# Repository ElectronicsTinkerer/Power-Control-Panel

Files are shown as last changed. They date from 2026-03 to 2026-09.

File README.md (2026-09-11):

# Custom Remote-Controlled Power Distribution Panel

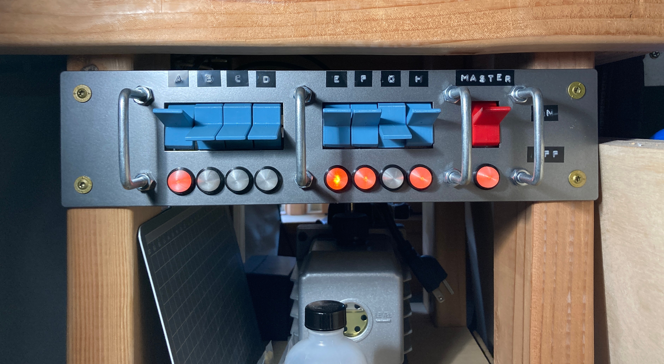
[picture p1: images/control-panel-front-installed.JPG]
Front image of the control panel, showing eight blue switches, grouped by fours, and a single red switch labeled "master" on the right side. Each group is separated by square U-bolts, acting as guards or handles to the panel. Below the switches are large orange indicator bulbs.


The control panel provides control over eight individually switched outlets for managing the numerous gizmoes plugged in to your workbench. In addition, there is a master switch which overrides the rest of the panel for shutting down all outputs.

The device is constructed of two components. The first (pictured above) is the control panel. This contains a PCB that uses a shift register to parallel load the state of the input switches and send them over an ethernet-style cable to the second component, the relay board. The relay board is responsible for generating the clock and load signals used by the control panel. It also shifts in the data from the control panel and drives a bank of eight relays to control attached devices.

All the design files are included in this repo. For more background and pictures, checkout [my website](https://zrcn.org/power-control-panel.html).

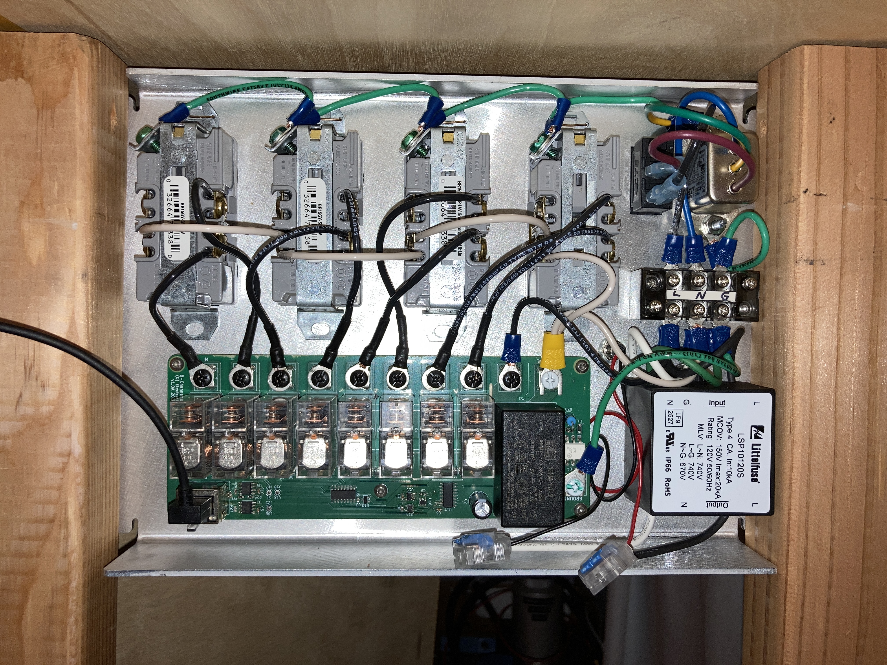
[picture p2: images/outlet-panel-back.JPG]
Relay board connected to outlets on the top side and protection circuitry on the right.

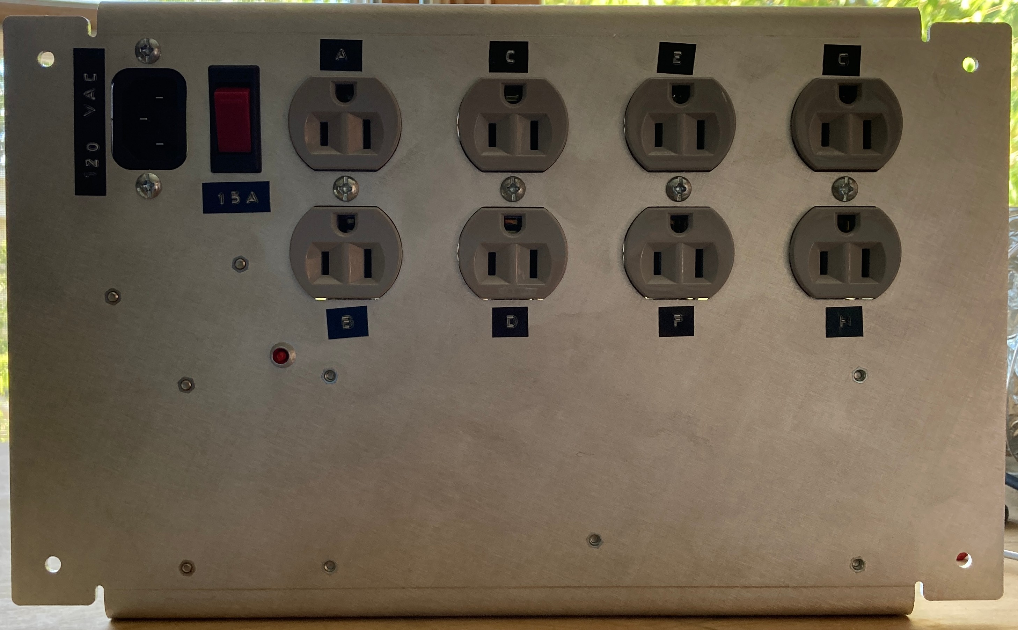
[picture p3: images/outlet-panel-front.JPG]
Front of the outlet panel, showing eight outlets, one IEC power inlet plug, the thermal breaker, and the surge supressor status light


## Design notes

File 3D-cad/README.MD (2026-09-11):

# 3D CAD

This directory contains all the 2D/3D models for components which are 3D printed or made from sheet metal.

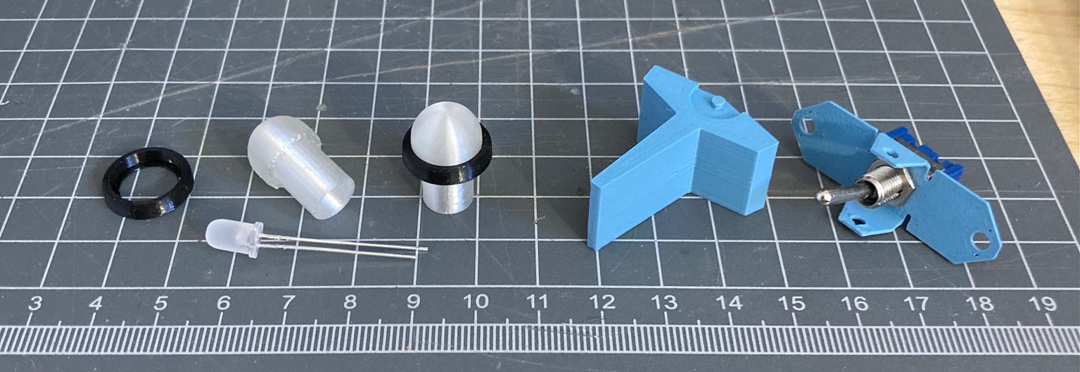
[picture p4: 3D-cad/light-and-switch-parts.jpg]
Image showing the 3D components in this directory against a 1cm grid.
 

```
.
├── 5mm-light-cover-decorator-ring.FCStd       # Black ring around the LED diffuser
├── 5mm-light-cover-decorator-ring-Fillet.step 
├── 5mm-light-cover.FCStd                      # LED diffuser
├── 5mm-light-cover-Revolve.step
├── Front-Panel-Assy.FCStd                     # Minimal assembly to check part alignment
├── Front-Panel.FCStd                          # User-facing front panel
├── Front-Panel-Unfold.dxf                     # FP. Order 0.1" sheet metal
├── Front-Panel-Rear-Plate.FCStd               # Mounting plate for switches and FP PCB
├── Front-Panel-Rear-Plate-Unfold.dxf          # FP PCB plate. 0.1" 5052 Al, K=0.4, R=0.125", 90 degree bend
├── Outlet-Panel.FCStd                         # Panel for Relay Board and Outlets.
├── Outlet-Panel-Assy.FCStd                    # Minimal assembly to check component alignment
├── Outlet-Panel-Unfold.dxf                    # Panel for Relay Board and Outlets. 0.1" 5052 Al, K-0.4 R=0.125", 90 degree bend, M3 hardware
├── Paddle-Switch-Bracket-Cut2.step            # Mount/pivot bracket for paddle switch
├── Paddle-Switch-Bracket-Cut.step             # Mount/pivot, slightly wider for 3D printing
├── Paddle-Switch-Bracket.FCStd
├── Paddle-Switch-Bracket-Unfold.dxf           # Mount/pivot. mild steel 0.03" thick K=0.36, 90 degree bends
├── Paddle-Switch-Bracket-inner-die.FCStd
├── Paddle-Switch-Bracket-inner-die-v1.0A0.step # "Die" for forming the Paddle-Switch-Bracket
├── Paddle-Switch-Cut.step                     # Paddle switch handle, "square"
├── Paddle-Switch.FCStd
├── Paddle-Switch-Fillet.step                  # Paddle switch handle, "rounded"
├── Relay-PCB-Insulator.FCStd                  # Electrical insulator for under the relay board
├── Relay-PCB-Insulator-Unfold.dxf             # 0.03" polypropylene
├── serial-relay-panel.FCStd                   # Reference (potentially out of date) 3D model of the relay PCB
├── serial-relay-panel.step
├── serial-switch-panel.FCStd                  # Reference (potentially out of date) 3D model of the input PCB
└── serial-switch-panel.step
```

Everything has been designed in FreeCAD, but this directory also contains the STEP file from the latest "working" version of the file so you shouldn't need to edit the FCStd files unless you want to tweak them.

## Print Settings

I have printed my copies in PETG (Prusa and Creality) and the following settings work well with a 0.4mm nozzle.

**light cover decorator ring**

* Color: black
* 0.1mm layer height.

**light cover**

* Color: translucent
* 0.1mm layer height
* Print facing upwards so it looks like a small mushroom. Use supports under the outer brim. No supports needed on the inside.
* 100% infill, concentric

**paddle switch bracket**

* Color: any ("Chalky blue" pictured above)
* 0.1mm layer height
* Add support material within the pivot holes on either side. You may need a 3/32" bit to clean the hole afterwards.
* Wait for the bed to cool completely before removing!
* Note: there is also a `.dxf` file if you want this made from sheet metal. See the dir listing comments for details.

**paddle switch bracket die**

* Color: any
* 0.15mm or smaller layer height
* 100% infil
* I used PETG, but I imagine other materials would work fine.
* This is not a piece used in the final assembly, but rather a tool to enable bending of the paddle switch bracket, should you decide to have it made from sheet metal. To do this, print the die and screw down the bracket to the die at one end plus the center hole. Make sure all holes are aligned. Now use a hammer and bend the tabs down until they are nearly flush with the sides of the die. I was able to get fairly consistent results at about 2-3 minute cycle time per switch bracket but YMMV. (Alternatively, just have the sheet metal fab house bend these).

**paddle switch**

* Color: any ("Chalky blue" pictured above)
* 0.1mm layer height
* Print on its side like the above image
* Use supports for all overhangs (around the pivot and the inside ledge)

## Non-printed items

To assemble the outlet panel, you'll need the following components:

* `LSP10120S` from Littelfuse (surge supressor, wire in parallel mode)
* `FL1M-6CW-4-R110V` or any other line voltage panel-mount indicator
* `3-2486200-9` from TE Connectivity or similar panel mount circuit breaker
* `15SRB8-W` from TE Connectivity or similar 15A IEC inlet plug

My recommended power cord is the `P007-006-15D` as it's rated for 15A and has a nice 90-degree plug for fitting behind the workbench.

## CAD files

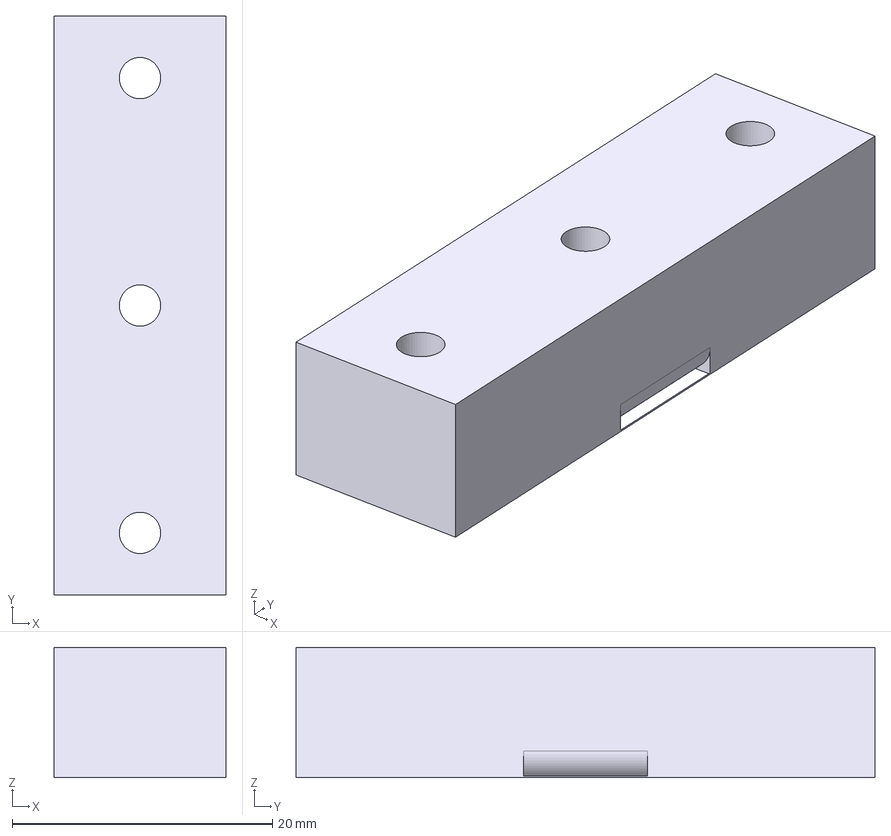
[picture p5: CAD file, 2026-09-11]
3D-cad/Paddle-Switch-Bracket-inner-die-v1.0A0.step
13.2 x 44.5 x 10.0 mm

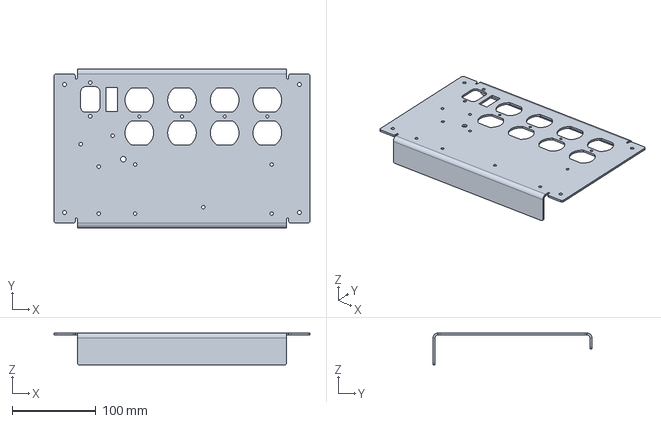
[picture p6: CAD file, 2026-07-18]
3D-cad/Outlet-Panel.FCStd
304.8 x 189.2 x 38.1 mm

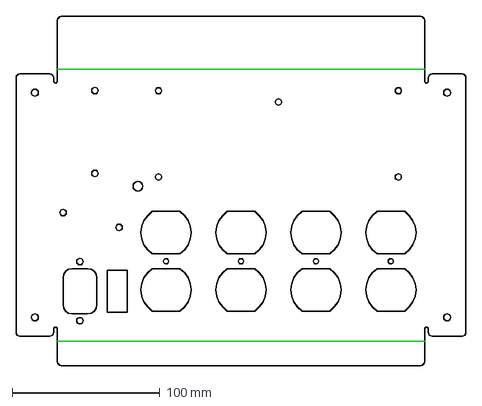
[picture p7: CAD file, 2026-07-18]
3D-cad/Outlet-Panel-Unfold.dxf
304.8 x 236.7 mm

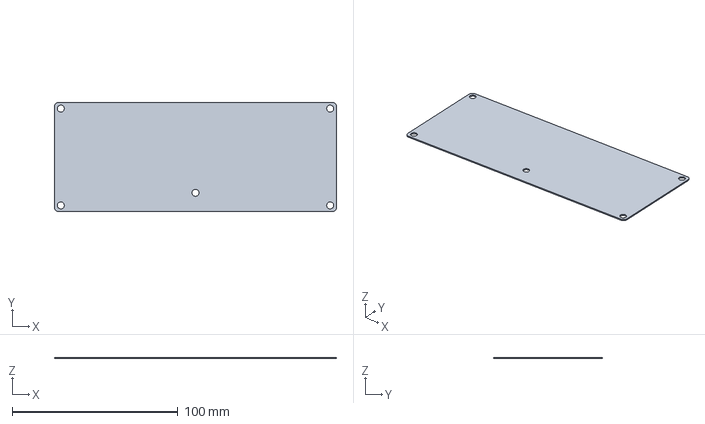
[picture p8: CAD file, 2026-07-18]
3D-cad/Relay-PCB-Insulator.FCStd
170.2 x 66.0 x 0.762 mm

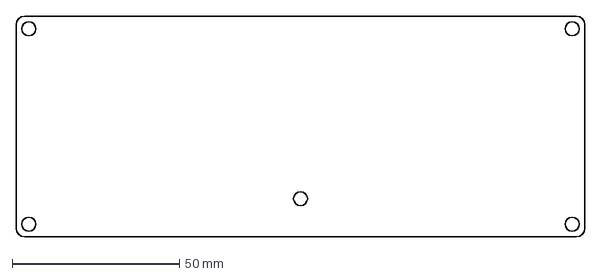
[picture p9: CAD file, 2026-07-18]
3D-cad/Relay-PCB-Insulator-Unfold.dxf
170.2 x 66.0 mm

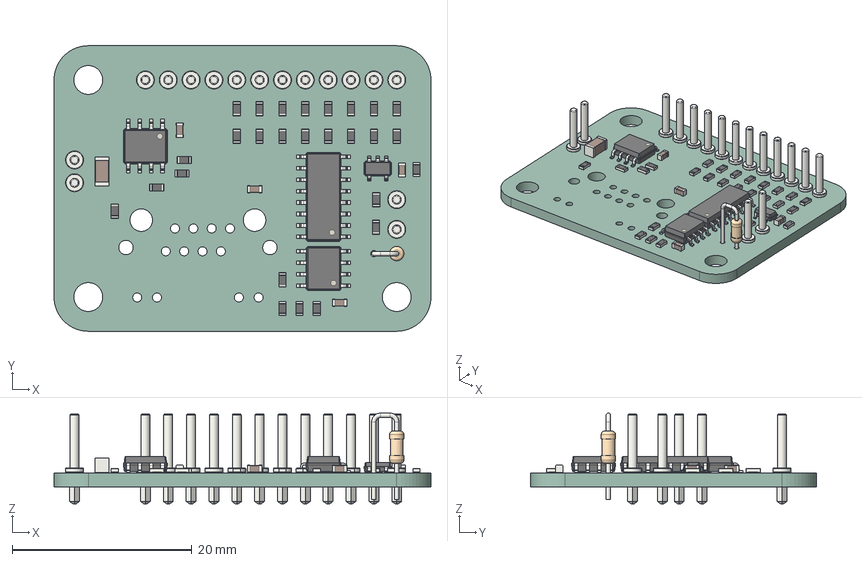
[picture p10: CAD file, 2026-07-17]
3D-cad/serial-switch-panel.step
41.9 x 31.8 x 10.1 mm
R_0603_1608Metric x 27
Pin_d1.0mm_L10.0mm x 16
C_0603_1608Metric x 4
SOIC-8_3.9x4.9mm_P1.27mm x 2
TSOP-5_1.65x3.05mm_P0.95mm
R_Axial_DIN0204_L36mm_D16mm_P254mm_Vertical
C_1206_3216Metric
SOIC-16_3.9x9.9mm_P1.27mm
serial-switch-panel_PCB

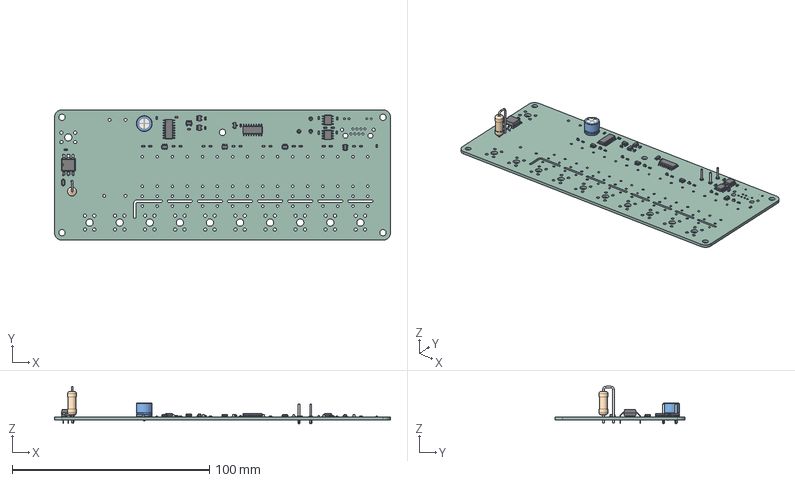
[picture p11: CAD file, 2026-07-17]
3D-cad/serial-relay-panel.step
170.2 x 66.0 x 19.0 mm
R_0603_1608Metric x 14
LED_0603_1608Metric x 8
C_Radial_D80mm_H70mm_P350mm
SC-74-6_1.55x2.9mm_P0.95mm x 4
SOIC-8_3.9x4.9mm_P1.27mm x 2
Pin_d1.0mm_L10.0mm x 3
SOT-23-5 x 3
C_0603_1608Metric x 8
R_Axial_DIN0414_L119mm_D45mm_P508mm_Vertical
DIP-6_W10.16mm
SOIC-16_3.9x9.9mm_P1.27mm x 2
D_SOD_123F
SOT-23-3
serial-relay-switch_PCB

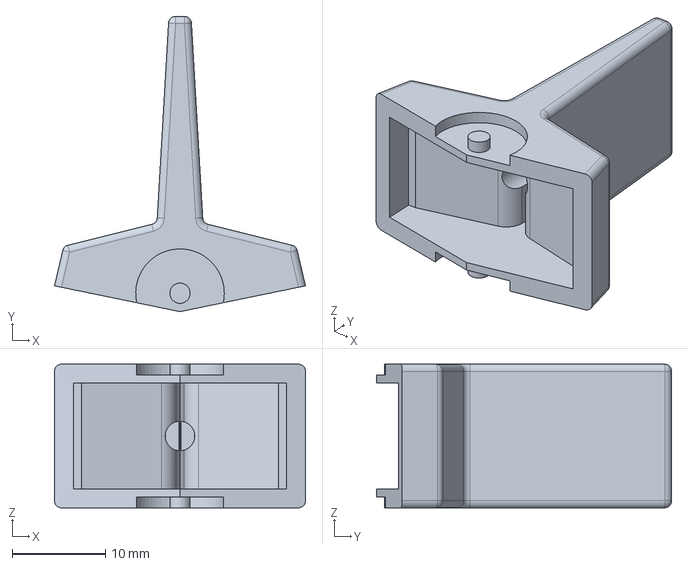
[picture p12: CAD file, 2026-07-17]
3D-cad/Paddle-Switch.FCStd
27.0 x 31.8 x 15.4 mm

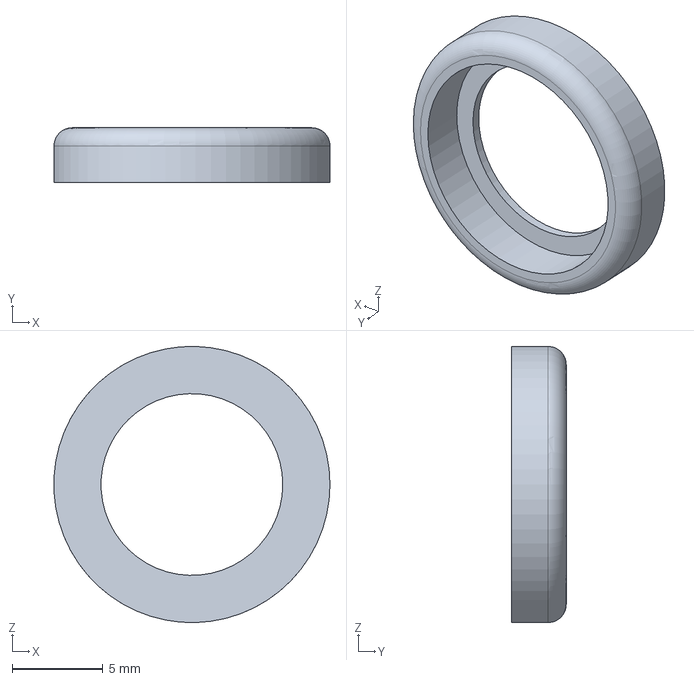
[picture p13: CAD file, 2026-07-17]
3D-cad/5mm-light-cover-decorator-ring.FCStd
15.2 x 3.00 x 15.2 mm

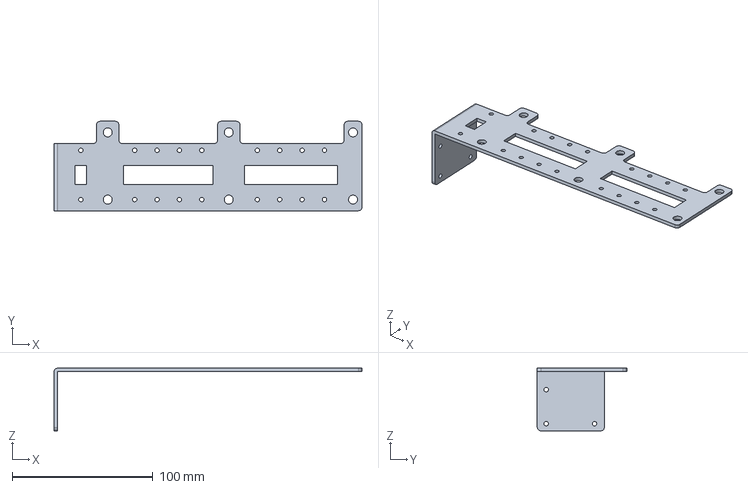
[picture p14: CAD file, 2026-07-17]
3D-cad/Front-Panel-Rear-Plate.FCStd
218.4 x 63.5 x 44.4 mm

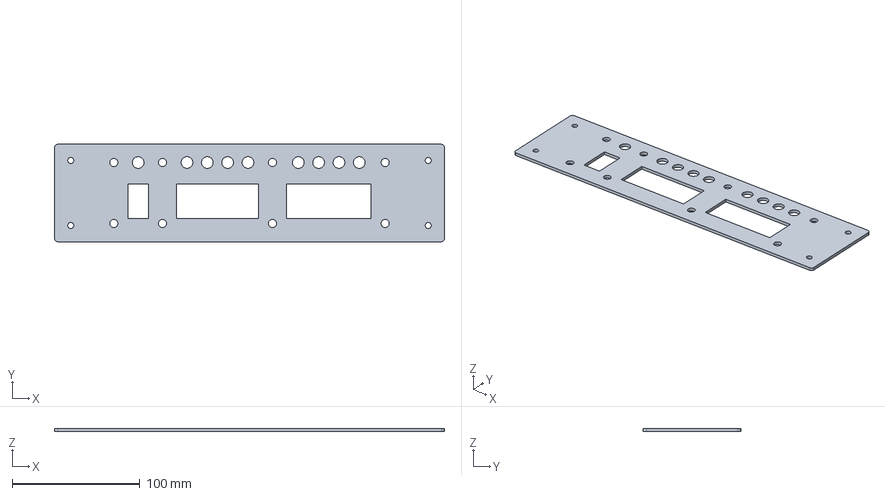
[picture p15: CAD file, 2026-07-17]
3D-cad/Front-Panel.FCStd
304.8 x 76.2 x 2.54 mm

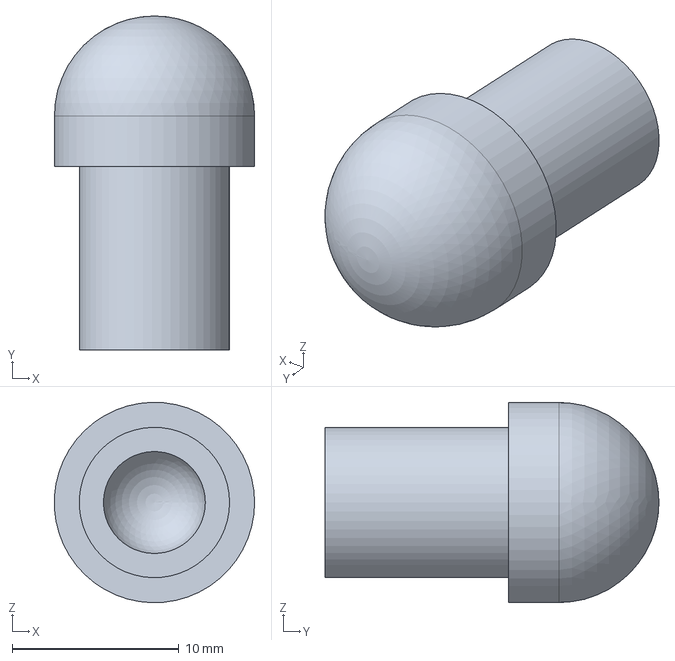
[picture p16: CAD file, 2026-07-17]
3D-cad/5mm-light-cover.FCStd
12.0 x 20.0 x 12.0 mm

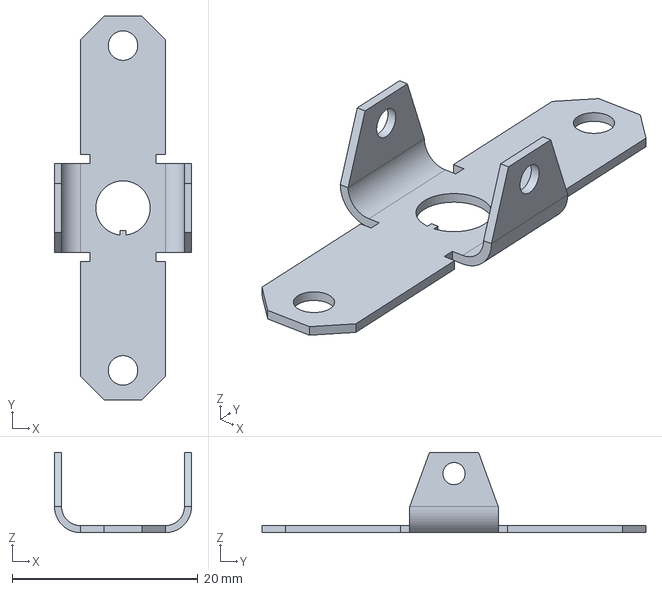
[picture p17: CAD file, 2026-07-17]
3D-cad/Paddle-Switch-Bracket.FCStd
14.7 x 41.3 x 8.64 mm

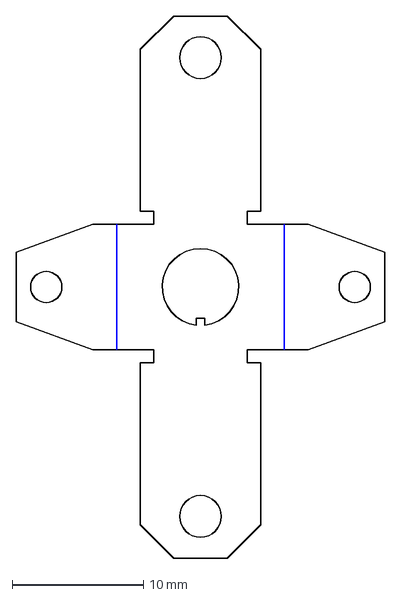
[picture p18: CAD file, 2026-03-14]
3D-cad/Paddle-Switch-Bracket-Unfold.dxf
28.1 x 41.3 mm

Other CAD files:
3D-cad/Outlet-Panel-Assy.FCStd
3D-cad/Front-Panel-Assy.FCStd
3D-cad/Paddle-Switch-Bracket-inner-die.FCStd
3D-cad/Front-Panel-Rear-Plate-Unfold.dxf
3D-cad/5mm-light-cover-Revolve.step
3D-cad/5mm-light-cover-decorator-ring-Fillet.step
3D-cad/Front-Panel-Unfold.dxf
3D-cad/Paddle-Switch-Bracket-Cut.step
3D-cad/Paddle-Switch-Bracket-Cut2.step
3D-cad/Paddle-Switch-Cut.step
3D-cad/Paddle-Switch-Fillet.step
3D-cad/serial-relay-panel.FCStd
3D-cad/serial-switch-panel.FCStd

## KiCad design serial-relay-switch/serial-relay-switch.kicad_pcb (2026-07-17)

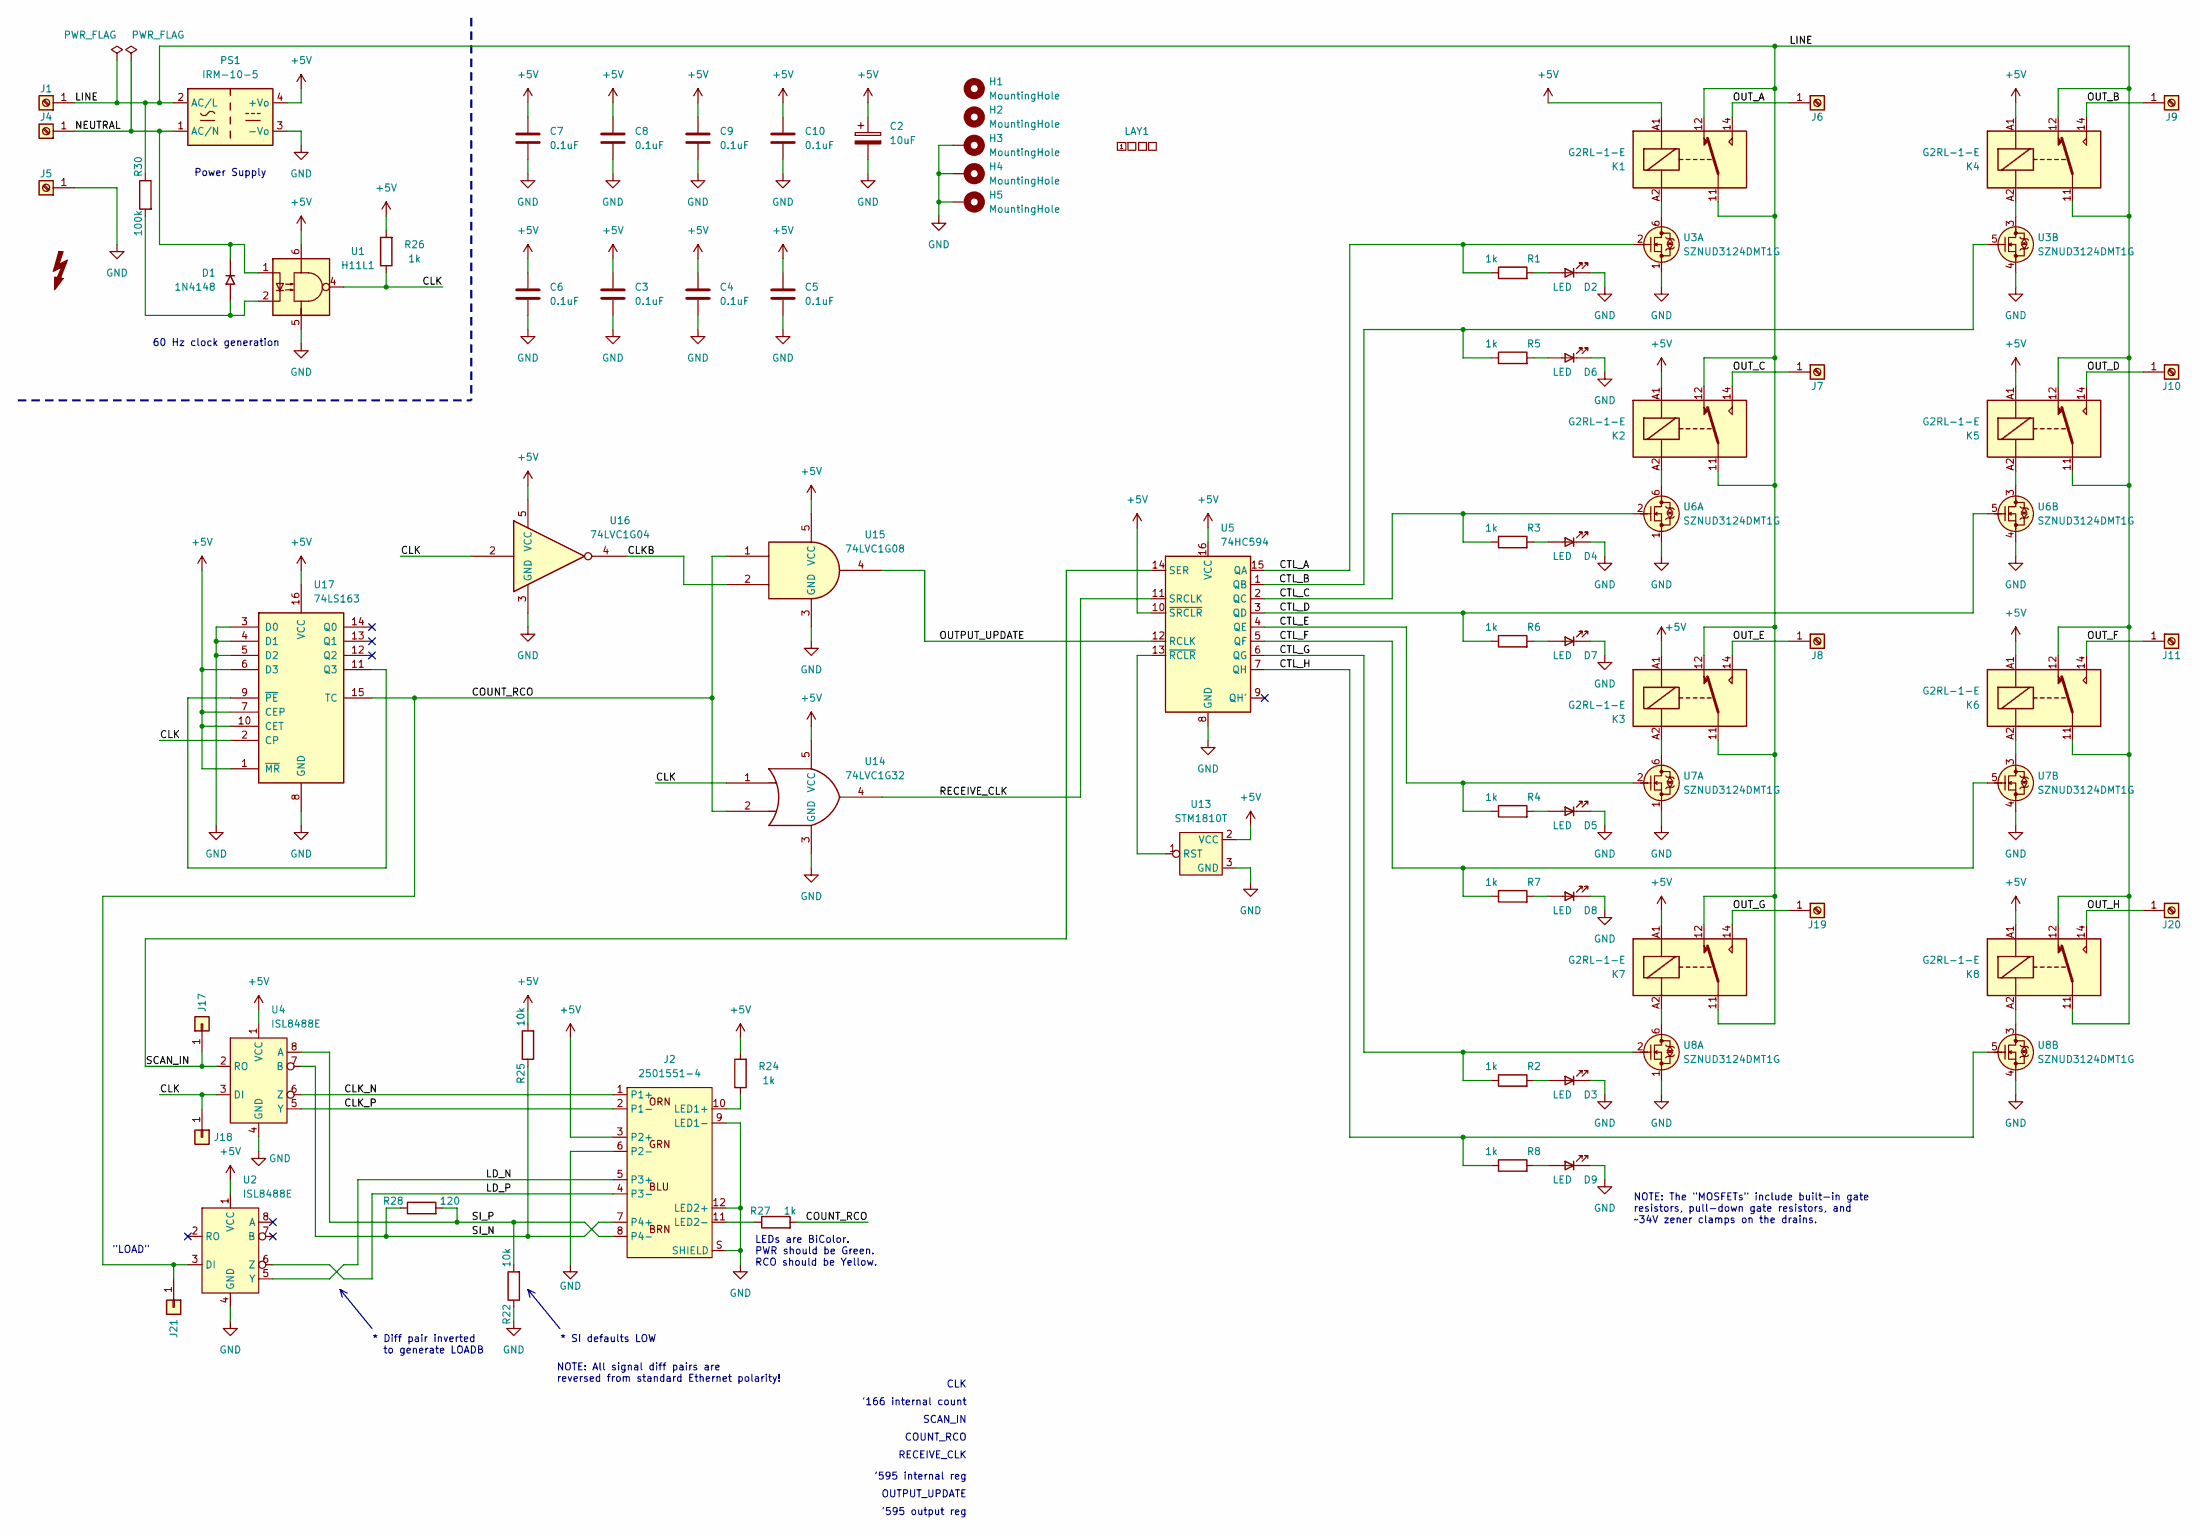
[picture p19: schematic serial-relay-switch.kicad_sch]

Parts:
C2: 10uF; C_Radial_D8.0mm_H7.0mm_P3.50mm
C3, C4, C5, C6, C7, C8, C9, C10: 0.1uF; C_0603_1608Metric
D1: 1N4148; D_SOD-123F
D2, D3, D4, D5, D6, D7, D8, D9: LED; LED_0603_1608Metric
H1, H2: MountingHole; MountingHole_3.2mm_M3_Keepout
H3, H5: MountingHole; MountingHole_3.2mm_M3_ISO14580_Pad_TopBottom
H4: MountingHole; MountingHole_3.2mm_M3_DIN965_Pad_TopBottom
J1, J4, J5, J6, J7, J8, J9, J10, J11, J19, J20: Screw_Terminal_01x01; ScrewTerminal_Keystone_8195
J2: 2501551-4; EthernetJack_TE_2501551-4
J17, J18, J21: Conn_01x01; Pin_D1.0mm
K1, K2, K3, K4, K5, K6, K7, K8: G2RL-1-E; Relay_SPDT_Omron_G2RL-1-E
LAY1: LayerMarker_2_3.81x2.54mm_TextH1mm_P1.27mm_BottomMirrored
PS1: IRM-10-5; Converter_ACDC_MeanWell_IRM-10-xx_THT
R1, R2, R3, R4, R5, R6, R7, R8, R24, R26, R27: 1k; R_0603_1608Metric
R22, R25: 10k; R_0603_1608Metric
R28: 120; R_0603_1608Metric
R30: 100k; R_Axial_DIN0414_L11.9mm_D4.5mm_P5.08mm_Vertical
U1: H11L1; DIP-6_W10.16mm_LongPads
U2, U4: ISL8488E; SOIC-8_3.9x4.9mm_P1.27mm
U3, U6, U7, U8: SZNUD3124DMT1G; SC-74-6_1.55x2.9mm_P0.95mm
U5: 74HC594; SOIC-16_3.9x9.9mm_P1.27mm
U13: STM1810T; SOT-23-3
U14: 74LVC1G32; SOT-23-5
U15: 74LVC1G08; SOT-23-5
U16: 74LVC1G04; SOT-23-5
U17: 74LS163; SOIC-16_3.9x9.9mm_P1.27mm

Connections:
+5V: C2.1, C3.1, C4.1, C5.1, C6.1, C7.1, C8.1, C9.1, C10.1, J2.3 (P2+), K1.A1, K2.A1, K3.A1, K4.A1, K5.A1, K6.A1, K7.A1, K8.A1, PS1.4 (+Vo), R24.2, R25.2, R26.2, U1.6, U2.1 (VCC), U4.1 (VCC), U5.10 (~SRCLR), U5.16 (VCC), U13.2 (VCC), U14.5 (VCC), U15.5 (VCC), U16.5 (VCC), U17.1 (~MR), U17.6 (D3), U17.7 (CEP), U17.10 (CET), U17.16 (VCC)
/CLK: J18.1 (Pin_1_1), R26.1, U1.4, U4.3 (DI), U14.1, U16.2, U17.2 (CP)
/CLKB: U15.2, U16.4
/CLK_N: J2.1 (P1+), U4.6 (Z)
/CLK_P: J2.2 (P1-), U4.5 (Y)
/COUNT_RCO: J21.1 (Pin_1_1), R27.2, U2.3 (DI), U14.2, U15.1, U17.15 (TC)
/CTL_A: R1.1, U3.2, U5.15 (QA)
/CTL_B: R5.1, U3.5, U5.1 (QB)
/CTL_C: R3.1, U5.2 (QC), U6.2
/CTL_D: R6.1, U5.3 (QD), U6.5
/CTL_E: R4.1, U5.4 (QE), U7.2
/CTL_F: R7.1, U5.5 (QF), U7.5
/CTL_G: R2.1, U5.6 (QG), U8.2
/CTL_H: R8.1, U5.7 (QH), U8.5
/LD_N: J2.5 (P3+), U2.5 (Y)
/LD_P: J2.4 (P3-), U2.6 (Z)
/LINE: J1.1 (Pin_1_1), K1.11, K1.12, K2.11, K2.12, K3.11, K3.12, K4.11, K4.12, K5.11, K5.12, K6.11, K6.12, K7.11, K7.12, K8.11, K8.12, PS1.2 (AC/L), R30.1
/NEUTRAL: D1.1 (K), J4.1 (Pin_1_1), PS1.1 (AC/N), U1.1
/OUTPUT_UPDATE: U5.12 (RCLK), U15.4
/OUT_A: J6.1 (Pin_1_1), K1.14
/OUT_B: J9.1 (Pin_1_1), K4.14
/OUT_C: J7.1 (Pin_1_1), K2.14
/OUT_D: J10.1 (Pin_1_1), K5.14
/OUT_E: J8.1 (Pin_1_1), K3.14
/OUT_F: J11.1 (Pin_1_1), K6.14
/OUT_G: J19.1 (Pin_1_1), K7.14
/OUT_H: J20.1 (Pin_1_1), K8.14
/RECEIVE_CLK: U5.11 (SRCLK), U14.4
/SCAN_IN: J17.1 (Pin_1_1), U4.2 (RO), U5.14 (SER)
/SI_N: J2.7 (P4+), R25.1, R28.1, U4.7 (B)
/SI_P: J2.8 (P4-), R22.2, R28.2, U4.8 (A)
GND: C2.2, C3.2, C4.2, C5.2, C6.2, C7.2, C8.2, C9.2, C10.2, D2.1 (K), D3.1 (K), D4.1 (K), D5.1 (K), D6.1 (K), D7.1 (K), D8.1 (K), D9.1 (K), H3.1 (1_1), H4.1 (1_1), H5.1 (1_1), J2.6 (P2-), J2.9 (LED1-), J2.12 (LED2+), J2.S (SHIELD), J5.1 (Pin_1_1), PS1.3 (-Vo), R22.1, U1.5, U2.4 (GND), U3.1, U3.4, U4.4 (GND), U5.8 (GND), U6.1, U6.4, U7.1, U7.4, U8.1, U8.4, U13.3 (GND), U14.3 (GND), U15.3 (GND), U16.3 (GND), U17.3 (D0), U17.4 (D1), U17.5 (D2), U17.8 (GND)
unnamed: D1.2 (A), R30.2, U1.2
unnamed: D2.2 (A), R1.2
unnamed: D3.2 (A), R2.2
unnamed: D4.2 (A), R3.2
unnamed: D5.2 (A), R4.2
unnamed: D6.2 (A), R5.2
unnamed: D7.2 (A), R6.2
unnamed: D8.2 (A), R7.2
unnamed: D9.2 (A), R8.2
unnamed: J2.10 (LED1+), R24.1
unnamed: J2.11 (LED2-), R27.1
unnamed: K1.A2, U3.6
unnamed: K2.A2, U6.6
unnamed: K3.A2, U7.6
unnamed: K4.A2, U3.3
unnamed: K5.A2, U6.3
unnamed: K6.A2, U7.3
unnamed: K7.A2, U8.6
unnamed: K8.A2, U8.3
unnamed: U5.13 (~RCLR), U13.1 (RST)
unnamed: U17.9 (~PE), U17.11 (Q3)

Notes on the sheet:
Power Supply
SCAN_IN
"LOAD"
'166 internal count
* Diff pair inverted to generate LOADB
* SI defaults LOW
60 Hz clock generation
NOTE: The "MOSFETs" include built-in gate resistors, pull-down gate resistors, and ~34V zener clamps on the drains.
CLK
COUNT_RCO
NOTE: All signal diff pairs are reversed from standard Ethernet polarity!
LEDs are BiColor. PWR should be Green. RCO should be Yellow.
'595 internal reg
'595 output reg
OUTPUT_UPDATE
RECEIVE_CLK

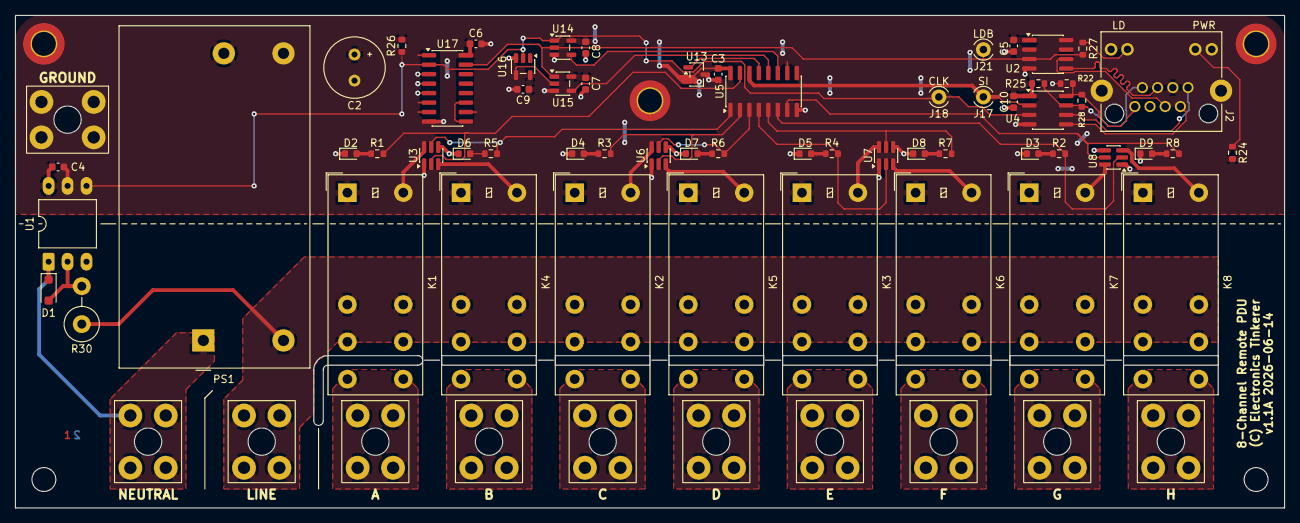
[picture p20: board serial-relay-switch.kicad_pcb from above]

Board: 2 copper layers, 170.2 x 66.0 mm, 76 parts (0 on the bottom side), 53 nets.

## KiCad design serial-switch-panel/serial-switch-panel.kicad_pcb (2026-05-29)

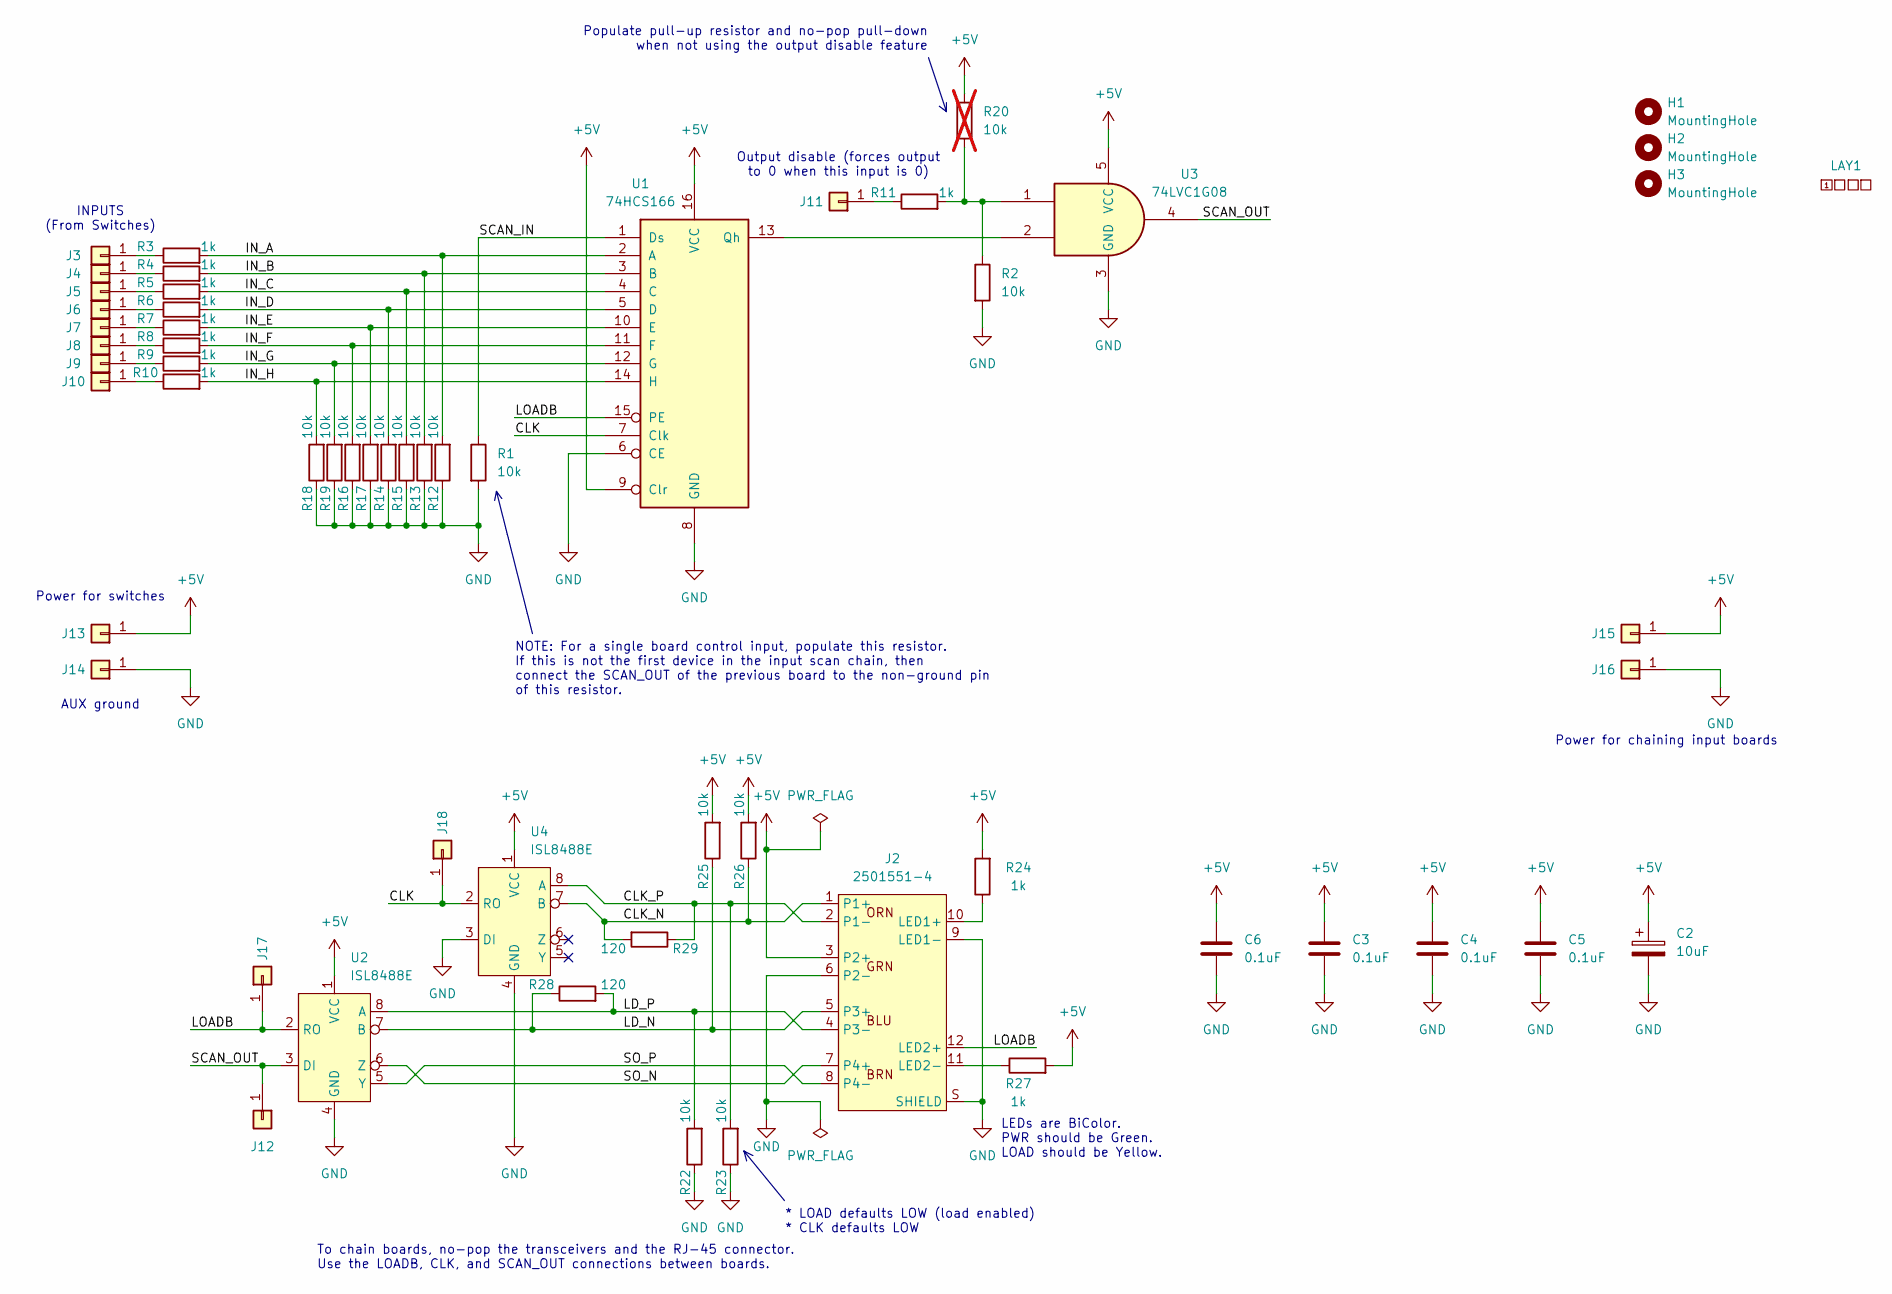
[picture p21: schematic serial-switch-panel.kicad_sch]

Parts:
C2: 10uF; C_1206_3216Metric
C3, C4, C5, C6: 0.1uF; C_0603_1608Metric
H1, H2, H3: MountingHole; MountingHole_3.2mm_M3
J2: 2501551-4
J3, J4, J5, J6, J7, J8, J9, J10, J11, J12, J13, J14, J15, J16, J17, J18: Conn_01x01; Pin_D1.0mm
LAY1: LayerMarker_2_3.81x2.54mm_TextH1mm_P1.27mm_BottomMirrored
R1: 10k; R_Axial_DIN0204_L3.6mm_D1.6mm_P2.54mm_Vertical
R2, R12, R13, R14, R15, R16, R17, R18, R19, R22, R23, R25, R26: 10k; R_0603_1608Metric
R3, R4, R5, R6, R7, R8, R9, R10, R11, R24, R27: 1k; R_0603_1608Metric
R20: 10k; R_0603_1608Metric; not fitted
R28, R29: 120; R_0603_1608Metric
U1: 74HCS166; SOIC-16_3.9x9.9mm_P1.27mm
U2, U4: ISL8488E; SOIC-8_3.9x4.9mm_P1.27mm
U3: 74LVC1G08; TSOP-5_1.65x3.05mm_P0.95mm

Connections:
+5V: C2.1, C3.1, C4.1, C5.1, C6.1, J2.3 (P2+), J13.1 (Pin_1_1), J15.1 (Pin_1_1), R20.1, R24.2, R25.2, R26.2, R27.2, U1.9 (Clr), U1.16 (VCC), U2.1 (VCC), U3.5 (VCC), U4.1 (VCC)
/CLK: J18.1 (Pin_1_1), U1.7 (Clk), U4.2 (RO)
/CLK_N: J2.1 (P1+), R26.1, R29.2, U4.7 (B)
/CLK_P: J2.2 (P1-), R23.2, R29.1, U4.8 (A)
/IN_A: R3.2, R12.2, U1.2 (A)
/IN_B: R4.2, R13.2, U1.3 (B)
/IN_C: R5.2, R15.2, U1.4 (C)
/IN_D: R6.2, R14.2, U1.5 (D)
/IN_E: R7.2, R17.2, U1.10 (E)
/IN_F: R8.2, R16.2, U1.11 (F)
/IN_G: R9.2, R19.2, U1.12 (G)
/IN_H: R10.2, R18.2, U1.14 (H)
/LD_N: J2.5 (P3+), R25.1, R28.1, U2.7 (B)
/LD_P: J2.4 (P3-), R22.2, R28.2, U2.8 (A)
/LOADB: J2.12 (LED2+), J17.1 (Pin_1_1), U1.15 (PE), U2.2 (RO)
/SCAN_IN: R1.1, U1.1 (Ds)
/SCAN_OUT: J12.1 (Pin_1_1), U2.3 (DI), U3.4
/SO_N: J2.7 (P4+), U2.6 (Z)
/SO_P: J2.8 (P4-), U2.5 (Y)
GND: C2.2, C3.2, C4.2, C5.2, C6.2, J2.6 (P2-), J2.9 (LED1-), J2.S (SHIELD), J14.1 (Pin_1_1), J16.1 (Pin_1_1), R1.2, R2.2, R12.1, R13.1, R14.1, R15.1, R16.1, R17.1, R18.1, R19.1, R22.1, R23.1, U1.6 (CE), U1.8 (GND), U2.4 (GND), U3.3 (GND), U4.3 (DI), U4.4 (GND)
unnamed: J2.10 (LED1+), R24.1
unnamed: J2.11 (LED2-), R27.1
unnamed: J3.1 (Pin_1_1), R3.1
unnamed: J4.1 (Pin_1_1), R4.1
unnamed: J5.1 (Pin_1_1), R5.1
unnamed: J6.1 (Pin_1_1), R6.1
unnamed: J7.1 (Pin_1_1), R7.1
unnamed: J8.1 (Pin_1_1), R8.1
unnamed: J9.1 (Pin_1_1), R9.1
unnamed: J10.1 (Pin_1_1), R10.1
unnamed: J11.1 (Pin_1_1), R11.1
unnamed: R2.1, R11.2, R20.2, U3.1
unnamed: U1.13 (Qh), U3.2

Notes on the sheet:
AUX ground
Power for chaining input boards
INPUTS (From Switches)
Power for switches
* LOAD defaults LOW (load enabled) * CLK defaults LOW
Populate pull-up resistor and no-pop pull-down when not using the output disable feature
NOTE: For a single board control input, populate this resistor. If this is not the first device in the input scan chain, then connect the SCAN_OUT of the previous board to the non-ground pin of this resistor.
To chain boards, no-pop the transceivers and the RJ-45 connector. Use the LOADB, CLK, and SCAN_OUT connections between boards.
LEDs are BiColor. PWR should be Green. LOAD should be Yellow.
Output disable (forces output to 0 when this input is 0)

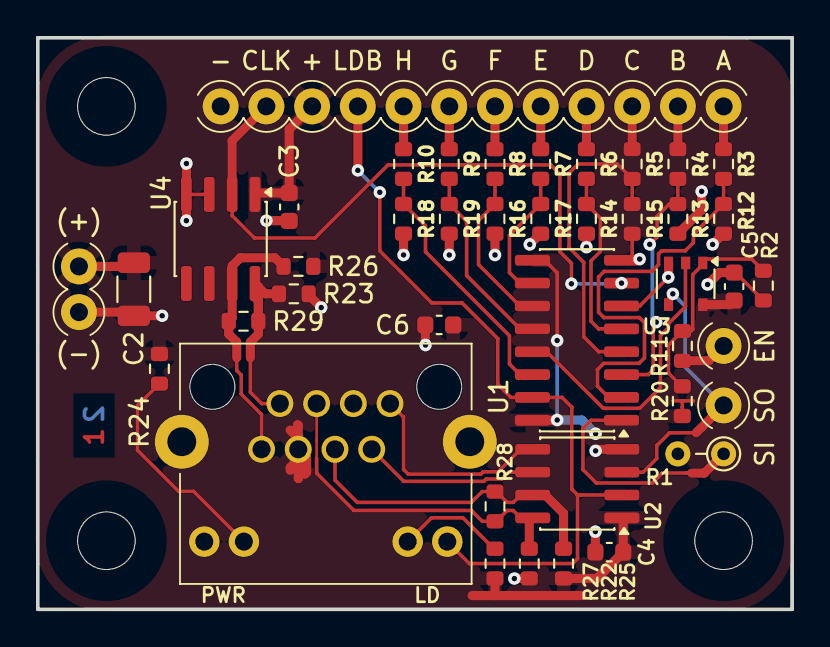
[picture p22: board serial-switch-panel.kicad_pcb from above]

Board: 2 copper layers, 41.9 x 31.8 mm, 58 parts (0 on the bottom side), 33 nets.

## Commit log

2026-02-15 Create front-panel schematic
    [serial-switch-panel.kicad_pcb, serial-switch-panel.kicad_sch]
2026-02-15 Fix front-panel sch ERC
    [serial-switch-panel.kicad_sch]
2026-02-15 Rough front-panel placement
    [serial-switch-panel.kicad_pcb, serial-switch-panel.kicad_sch]
2026-02-15 Final? front-panel placement
    [serial-switch-panel.kicad_pcb]
2026-02-15 [fp] Correct P4+/- swap in ethernet connector
    [serial-switch-panel.kicad_pcb, serial-switch-panel.kicad_sch]
2026-02-15 [fp] Complete board route
    Note: lots of DRC errors & warnings.
    - Warnings are silk overlaps - these are fine
    - Most errors are clearance violations on the shift register - waving these as still > 6mil
    - Remaining errors are thermal spokes on non-critical components & fill regions
    [serial-switch-panel.kicad_pcb, serial-switch-panel.kicad_sch]
2026-02-16 [rs] Start relay switch board
    [serial-relay-switch.kicad_pcb, serial-relay-switch.kicad_sch]
2026-02-16 [rs] Most of schematic complete
    [serial-relay-switch.kicad_sch]
2026-02-16 [rs] Complete schematic
    [serial-relay-switch.kicad_sch]
2026-02-16 [rs] Footprint assignment
    [serial-relay-switch.kicad_sch]
2026-02-16 [rs] Mostly complete preliminary PCB placement
    [serial-relay-switch.kicad_pcb, serial-relay-switch.kicad_sch]
2026-02-16 [rs] New preliminary board layout
    [serial-relay-switch.kicad_pcb, serial-relay-switch.kicad_sch]
2026-02-17 [rs] Routing progress
    [serial-relay-switch.kicad_pcb]
2026-02-17 [rs] Routed, save for the pesky "Unrouted 1"
    [serial-relay-switch.kicad_pcb, serial-relay-switch.kicad_sch]
2026-02-17 [rs] Silk cleanup
    [serial-relay-switch.kicad_pcb]
2026-02-17 [rs] Ready for review
    [serial-relay-switch.kicad_pcb]
2026-02-28 [3d] Add 3D files for LED covers/mounts and Paddle Switches
    [5mm-light-cover-Revolve.step, 5mm-light-cover-decorator-ring-Fillet.step, 5mm-light-cover-decorator-ring.FCStd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]
2026-03-01 [3d] Document 3D directory contents
    Create README.MD
    Create 'rounded' version of paddle switch handle
    Add real picture of printed parts
    [Paddle-Switch-Fillet.step, Paddle-Switch.FCStd]
2026-03-06 [fp] Add dimensions to mounting holes
    [serial-switch-panel.kicad_pcb]
2026-03-06 [fp][rs] Change hole footprints to no soldermask
    [serial-relay-switch.kicad_pcb, serial-relay-switch.kicad_sch, serial-switch-panel.kicad_pcb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]
2026-03-06 [fp] Add PCB dimensions to drawing layer
    [serial-switch-panel.kicad_pcb]
2026-03-06 [3d] Design Front panel sheet metal components
    [5mm-light-cover-decorator-ring.FCStd, 5mm-light-cover.FCStd, Front-Panel-Assy.FCStd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]
2026-03-07 [3d] Move Front Panel mount holes; export FP DXF
    [Front-Panel-Assy.FCStd, Front-Panel-Unfold.dxf, Front-Panel.FCStd]
2026-03-07 [3d] Export FP rear DXF
    [5mm-light-cover-decorator-ring.FCStd, 5mm-light-cover.FCStd, Front-Panel-Assy.FCStd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]
2026-03-07 [fp] Check/Finalize PCB
    [serial-switch-panel.kicad_pcb]
2026-03-07 [fp] Export gerbers v1.0A0
    [serial-switch-panel.kicad_pcb]
2026-03-08 [rs] Check/Finalize PCB; Export gerbers v1.0A0
    [serial-relay-switch.kicad_pcb, serial-relay-switch.kicad_sch]
2026-03-08 [3d] Create Outlet Panel
    [Outlet-Panel.FCStd]
2026-03-08 [3d] Export outlet panel DXF
    [Outlet-Panel-Unfold.dxf, Outlet-Panel.FCStd]
2026-03-09 [3d] Add insulator for relay PCB
    [Relay-PCB-Insulator-Unfold.dxf, Relay-PCB-Insulator.FCStd]
2026-03-09 [rs] Add RJ-45 shield connection; Export v1.0A1 gerbers
    [serial-relay-switch.kicad_pcb, serial-relay-switch.kicad_sch]
2026-03-09 [fp] Add RJ-45 shield connection
    [serial-switch-panel.kicad_pcb, serial-switch-panel.kicad_sch]
2026-03-10 [fp] Change '166 to SOIC-16 footprint; Export v1.0A1 gerbers
    Wow, that one is tight (!)
    [serial-switch-panel.kicad_pcb, serial-switch-panel.kicad_sch]
2026-03-14 [3d] Re-export paddle switch bracket DXF
    [Paddle-Switch-Bracket-Unfold.dxf]
2026-05-18 [rs] Add PoR; Change to SC-74 coil driver package
    [serial-relay-switch.kicad_pcb, serial-relay-switch.kicad_sch]
2026-05-18 [rs] Route 97cfebe + export v1.0A2 gerbers
    [serial-relay-switch.kicad_pcb]
2026-05-18 [fp] Update schematic to kicad 10.0.2
    [serial-switch-panel.kicad_sch]
2026-05-29 [rs] Update DRC rules; bump PCB to v1.0B
    [serial-relay-switch.kicad_pcb, serial-relay-switch.kicad_sch]
2026-05-29 [fp] Update DRC rules; bump PCB to v1.0B
    [serial-switch-panel.kicad_pcb]
2026-06-15 [rs] Add missing pullup on CLK; bump to v1.1A
    [serial-relay-switch.kicad_pcb, serial-relay-switch.kicad_sch]
2026-07-06 [rs] Correct timing in LOADB signal
    Moved the LOAD signal to be from the counter's
    RCO instead of the MSb of the count. This moves
    the load pulse one clock cycle earlier and corrects
    an off-by-one error in the receive shift register
    timing, causing relay H to not be controllable
    [serial-relay-switch.kicad_pcb, serial-relay-switch.kicad_sch]
2026-07-17 [3d] Update to FreeCAD 1.1.1
    [5mm-light-cover-decorator-ring.FCStd, 5mm-light-cover.FCStd, Front-Panel-Assy.FCStd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]
2026-07-17 [rs][fp][3d] Export 3D PCB STEP files
    [serial-relay-panel.step, serial-relay-switch.kicad_pcb, serial-switch-panel.step]
2026-07-17 [3d] Add PCB to front panel Assy
    [Front-Panel-Assy.FCStd, serial-relay-panel.FCStd, serial-switch-panel.FCStd]
2026-07-18 [3d] Enlarge Relay Insulator holes to SO-M3-6 standoff OD
    [Relay-PCB-Insulator-Unfold.dxf, Relay-PCB-Insulator.FCStd]
2026-07-18 [3d] Create outlet panel Assy for test fit
    Also add top bend to outlet panel for greater stiffness
    against bending during plug insertion and removal.
    [Outlet-Panel-Assy.FCStd, Outlet-Panel-Unfold.dxf, Outlet-Panel.FCStd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]
2026-09-07 [3d] create form for bending brackets
    [Paddle-Switch-Bracket-inner-die.FCStd]
2026-09-11 [3d] Add paddle switch bracket inner die to README
    [Paddle-Switch-Bracket-inner-die-v1.0A0.step]
